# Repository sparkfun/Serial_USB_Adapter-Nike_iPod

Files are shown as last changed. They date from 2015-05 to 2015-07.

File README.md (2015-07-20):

**NOTE: This product has been retired from our catalog and is no longer for sale. This page is made available for those looking for datasheets and the simply curious.**

SparkFun Serial to USB Adapter - Nike+iPod
========================================

SparkFun Serial to USB Adapter - Nike+iPod

[*SparkFun Serial to USB Adapter - Nike+iPod (DEV-08245)*](https://www.sparkfun.com/products/8245)

This is a simple USB serial interface to mate with the Nike+iPod product. 
Use this breakout board to send and receive serial commands to the receiver and listen for individual foot pods. 
This will allow easy creation of proximity based projects and running/workout research. 
VCC (3.3V), ground, and iPod TX and RX are brought out to a standard header so that you can connect this board to a microcontroller.

Repository Contents
-------------------

* **/Firmware** - Example code 
* **/Hardware** - Eagle design files (.brd, .sch)
* **/Production** - Production panel files (.brd)

Documentation
--------------
* **[Hookup Guide](https://www.sparkfun.com/tutorials/41)** - Basic hookup guide for the adapter.
* **[SparkFun Fritzing repo](https://github.com/sparkfun/Fritzing_Parts)** - Fritzing diagrams for SparkFun products.
* **[SparkFun 3D Model repo](https://github.com/sparkfun/3D_Models)** - 3D models of SparkFun products. 

License Information
-------------------
This product is _**open source**_! 

The **hardware** is released under [Creative Commons ShareAlike 4.0 International](https://creativecommons.org/licenses/by-sa/4.0/).

Please use, reuse, and modify these files as you see fit. Please maintain attribution to SparkFun Electronics and release anything derivative under the same license.

Distributed as-is; no warranty is given.

- Your friends at SparkFun.

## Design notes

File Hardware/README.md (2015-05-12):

SparkFun <PRODUCT NAME> Design Files
=====================================

The .sch and .brd files hare are Eagle CAD schematic and PCB design files from SparkFun Electronics.
A freeware version of Eagle can be found [here](http://www.cadsoftusa.com/download-eagle/freeware/). 

License
---------
This product is open source! 
The hardware is released under [Creative Commons ShareAlike 4.0 International](https://creativecommons.org/licenses/by-sa/4.0/).

Please use, reuse, and modify these files as you see fit. Please maintain attribution to SparkFun Electronics and release anything derivative under the same license.

Distributed as-is; no warranty is given.

- Your friends at SparkFun.

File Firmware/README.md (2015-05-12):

SparkFun Serial to USB Adapter- Nike+iPod Firmware
==================================================

* **Nike_iPod_Serial** - Visual Basic  examples
* **VB-Extras** - Visual Basic  extra files for work on the adapter board.

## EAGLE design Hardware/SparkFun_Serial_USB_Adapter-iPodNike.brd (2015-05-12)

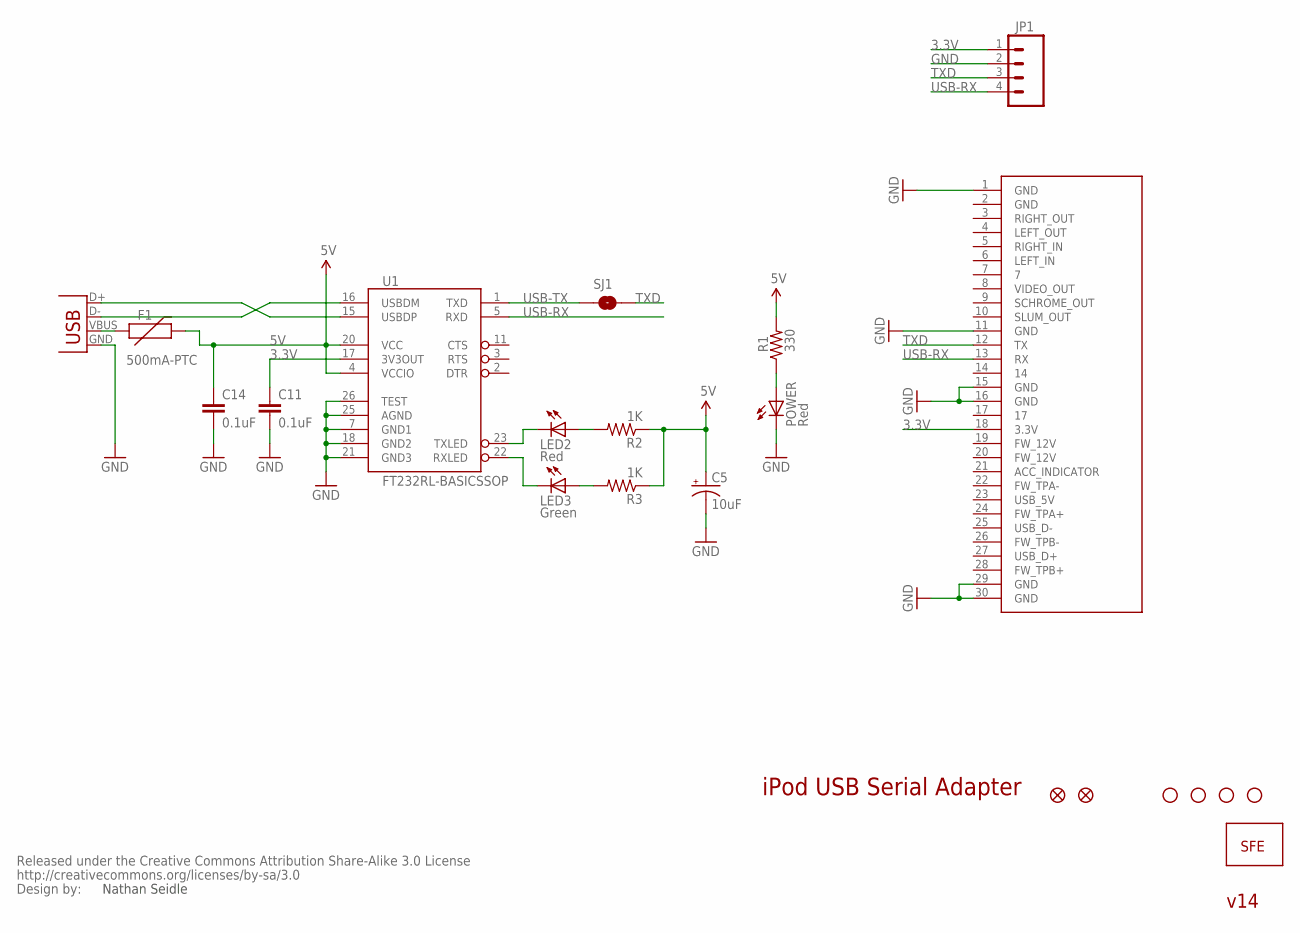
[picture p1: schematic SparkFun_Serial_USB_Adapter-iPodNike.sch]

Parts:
C5: 10uF; EIA3216
C11, C14: 0.1uF; C0402
F1: 500mA-PTC; PTC-1206
JP1: M04PTH; 1X04
LED2: Red; LED-0603
LED3: Green; LED-0603
POWER: Red; LED-0603
R1: 330; C0402
R2, R3: 1K; C0402
SJ1: SOLDERJUMPERNC2; SJ_2S
U1: FT232RL-BASICSSOP; SSOP28DB
U$1, U$5, U$6, U$7: STAND-OFF
U$2: IPOD_CONNECTOR_FEMALE; IPOD_FEMALE_CONNECTOR
U$3: LOGO-SFENEW; SFE-NEW-WEBLOGO
U$4, U$8: FIDUCIAL1X2; FIDUCIAL-1X2
U$9: CREATIVE_COMMONS
X1: USBSMD; USB-MINIB

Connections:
3.3V: C11.1, JP1.1, U1.17 (3V3OUT), U$2.18 (3.3V)
5V: C5.A (+), C14.1, F1.2, R1.2, R2.1, R3.1, U1.4 (VCCIO), U1.20 (VCC)
GND: C5.C (-), C11.2, C14.2, JP1.2, POWER.C, U1.7 (GND1), U1.18 (GND2), U1.21 (GND3), U1.25 (AGND), U1.26 (TEST), U$2.1 (GND), U$2.11 (GND), U$2.15 (GND), U$2.16 (GND), U$2.29 (GND), U$2.30 (GND), X1.GND
unnamed: POWER.A, R1.1
unnamed: U1.15 (USBDP), X1.D+
unnamed: LED2.A, R2.2
unnamed: LED3.A, R3.2
unnamed: U1.16 (USBDM), X1.D-
RXLED: LED3.C, U1.22 (RXLED)
TXD: JP1.3, SJ1.2, U$2.12 (TX)
TXLED: LED2.C, U1.23 (TXLED)
USB-RX: JP1.4, U1.5 (RXD), U$2.13 (RX)
USB-TX: SJ1.1, U1.1 (TXD)
USBVCC: F1.1, X1.VBUS

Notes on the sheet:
iPod USB Serial Adapter
Nathan Seidle
v14

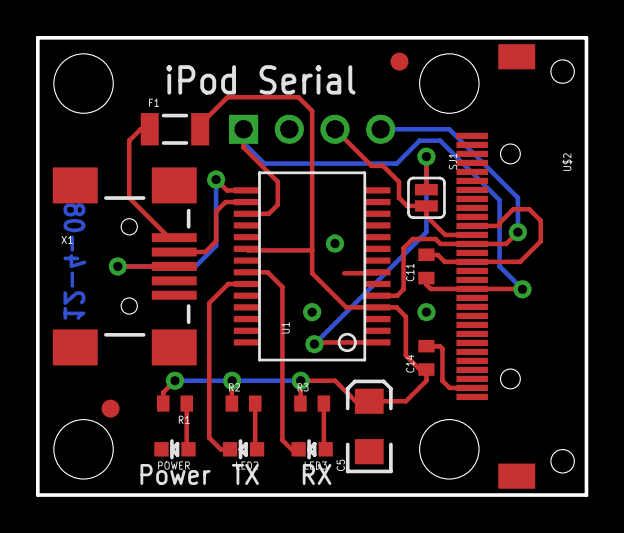
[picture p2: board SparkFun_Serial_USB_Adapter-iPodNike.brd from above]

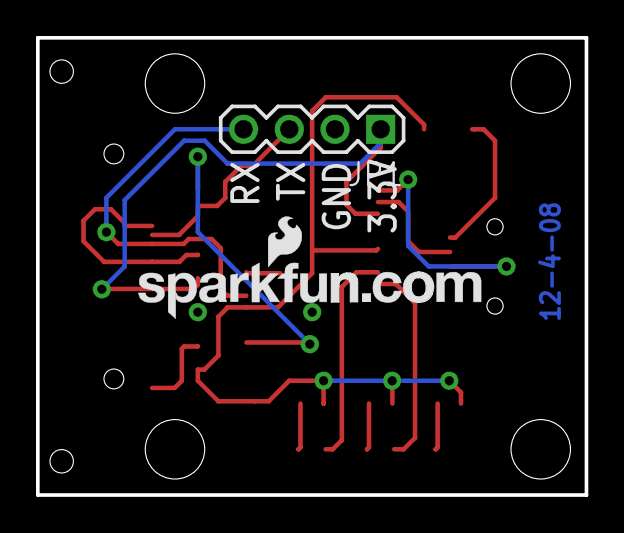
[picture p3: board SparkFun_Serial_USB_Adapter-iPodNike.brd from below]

Board: 2 copper layers, 30.5 x 25.4 mm, 23 parts (2 on the bottom side), 14 nets.

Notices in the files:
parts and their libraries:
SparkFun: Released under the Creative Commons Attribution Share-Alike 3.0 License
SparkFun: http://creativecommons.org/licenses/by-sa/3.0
